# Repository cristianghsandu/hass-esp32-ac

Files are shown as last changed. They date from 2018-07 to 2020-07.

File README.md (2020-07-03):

# ESP32 Home Sensor: AC Control #

## General info ##
This is a small board to add Home Assistant control to your old school AC.  
It uses an ESP32 for WiFi connectivity and IR code sending(via the RMT peripheral).  

This is what it looks like when fully built:  

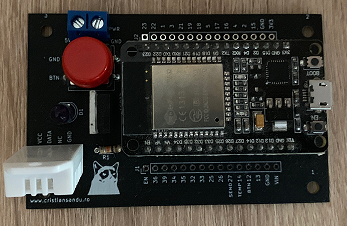
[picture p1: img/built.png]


And this is the bare PCB:  

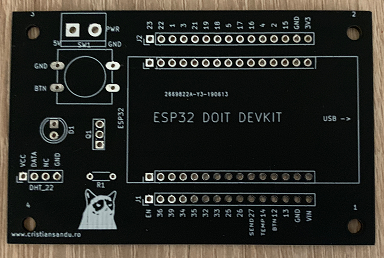
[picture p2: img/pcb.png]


## Building ##
For a Fritzing breadboard schematic see [this Fritzing file](schematic/schematic.fzz).  
For the PCB I used the ESP32 30-pin DoIT devkit board footprint from this [repo](https://github.com/RuiSantosdotme/ESP32-Weather-Shield-PCB).  

The KiCad sources for the PCB are in [this folder](pcb/esp32-ac-board).  

### BOM ###
  
The very few parts you will need are:  

- An ESP32 Doit Devkit v1 (the 30 pin version see [this](https://randomnerdtutorials.com/getting-started-with-esp32/))  
- A NPN transistor in a TO220 package(you could change the design to use a TO92 transistor) like the [2N5296](https://www.mouser.com/ds/2/68/2n5294-46674.pdf)  
- Some male and female pin headers(pitch 2.54'')
- A 12x12mm push button  
- An IR LED
- A DHT22 humidity and temperature sensor  
- A 10k pull up resistor for the DHT22 sensor
- Optional: a 2 pin screw terminal for powering the board externally

### The Code ###

I am using ESP Home to build the firmware [ESP Home](https://esphome.io/).  
The "code" is in this file: [esphome/ac-living.yml](esphome/ac-living.yml).    

### AC Control ###

To control your AC you will need to change the RAW codes in the [config.h](src/config.h) file. I used [AnalysIR](https://www.analysir.com/) to get my raw codes but you could also get them with an Arduinoor even Lirc with irrecord(it's what I initially did). Hardware wise you will either need an Arduino/Raspberry Pi + TSOP4838 receiver(or any other receiver) or maybe an all-in-one solution like the [USB IR Toy](http://dangerousprototypes.com/docs/USB_Infrared_Toy) - which I already had and used.

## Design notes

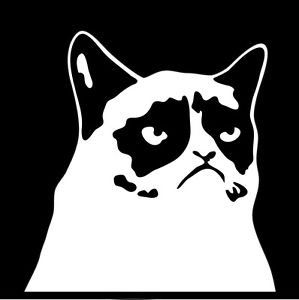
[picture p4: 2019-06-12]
img/grumpy.jpg

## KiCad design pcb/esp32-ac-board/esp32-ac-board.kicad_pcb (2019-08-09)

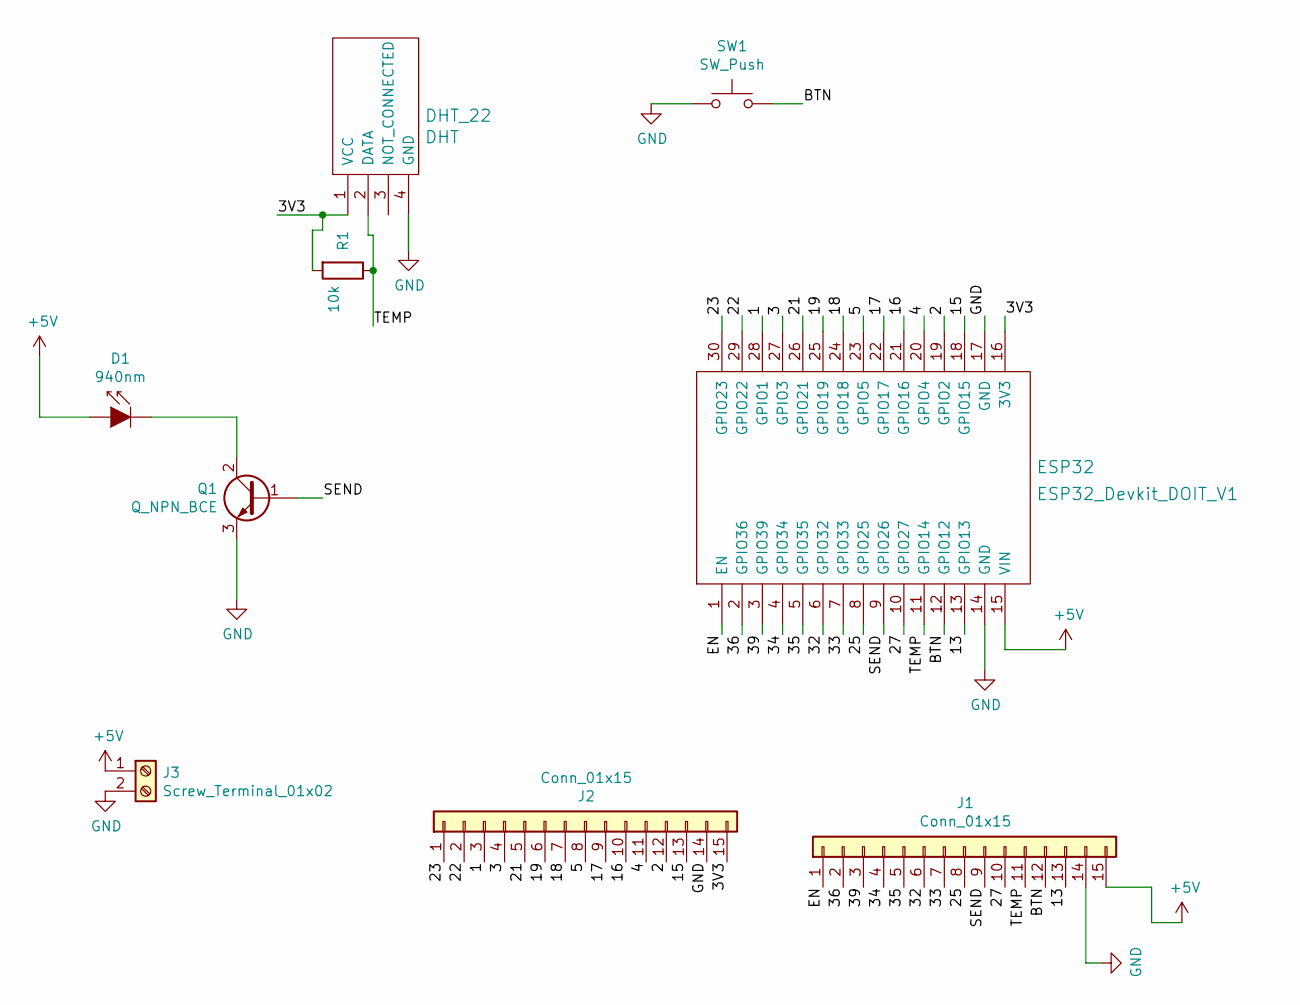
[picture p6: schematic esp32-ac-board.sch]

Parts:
D1: 940nm; LED_D5.0mm_IRGrey
DHT_22: DHT
ESP32: ESP32_Devkit_DOIT_V1
J1, J2: Conn_01x15; PinHeader_1x15_P2.54mm_Vertical
J3: Screw_Terminal_01x02; TerminalBlock_bornier-2_P5.08mm
Q1: Q_NPN_BCE; TO-251-3_Vertical
R1: 10k; R_Axial_DIN0204_L3.6mm_D1.6mm_P5.08mm_Horizontal
SW1: SW_Push; SW_PUSH-12mm_Wuerth-430476085716

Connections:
+5V: D1.2 (A), ESP32.15 (VIN), J1.15, J3.1
/1: ESP32.28 (GPIO1), J2.3
/2: ESP32.19 (GPIO2), J2.12
/3: ESP32.27 (GPIO3), J2.4
/3V3: DHT_22.1 (VCC), ESP32.16 (3V3), J2.15, R1.2
/4: ESP32.20 (GPIO4), J2.11
/5: ESP32.23 (GPIO5), J2.8
/13: ESP32.13 (GPIO13), J1.13
/15: ESP32.18 (GPIO15), J2.13
/16: ESP32.21 (GPIO16), J2.10
/17: ESP32.22 (GPIO17), J2.9
/18: ESP32.24 (GPIO18), J2.7
/19: ESP32.25 (GPIO19), J2.6
/21: ESP32.26 (GPIO21), J2.5
/22: ESP32.29 (GPIO22), J2.2
/23: ESP32.30 (GPIO23), J2.1
/25: ESP32.8 (GPIO25), J1.8
/27: ESP32.10 (GPIO27), J1.10
/32: ESP32.6 (GPIO32), J1.6
/33: ESP32.7 (GPIO33), J1.7
/34: ESP32.4 (GPIO34), J1.4
/35: ESP32.5 (GPIO35), J1.5
/36: ESP32.2 (GPIO36), J1.2
/39: ESP32.3 (GPIO39), J1.3
/BTN: ESP32.12 (GPIO12), J1.12, SW1.2
/EN: ESP32.1 (EN), J1.1
/SEND: ESP32.9 (GPIO26), J1.9, Q1.1 (B)
/TEMP: DHT_22.2 (DATA), ESP32.11 (GPIO14), J1.11, R1.1
GND: DHT_22.4 (GND), ESP32.14 (GND), ESP32.17 (GND), J1.14, J2.14, J3.2, Q1.3 (E), SW1.1
unnamed: D1.1 (K), Q1.2 (C)

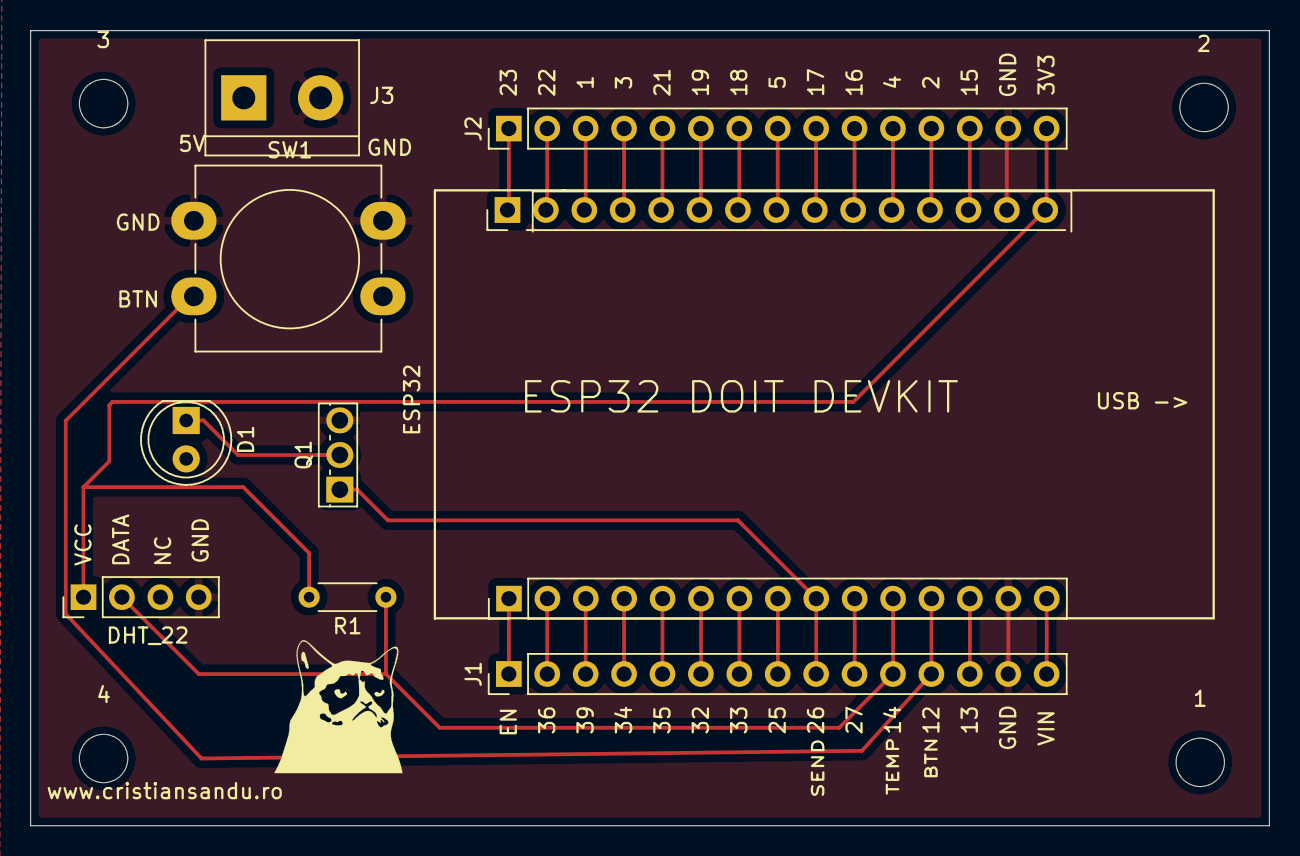
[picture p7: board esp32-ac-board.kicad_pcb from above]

Board: 2 copper layers, 81.9 x 52.6 mm, 14 parts (1 on the bottom side), 30 nets.

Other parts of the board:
1, 2, 3, 4: MountingHole_3.2mm_M3
LOGO: LOGO; Logo

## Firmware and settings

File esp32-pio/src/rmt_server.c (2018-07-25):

/* RMT transmit control over http server.
	* 
	* HTTP server code modified from
	* https://github.com/feelfreelinux/myesp32tests/blob/master/examples/http_server.c
	* That software is distributed under GNU General Public License
	* 
	* RMT code modified from example: rmt_nec_tx_rx
	* That software is distributed under Public Domain (or CC0 licensed, at your option.)
	* 
	* Additional software included in this application is distributed under
	* Public Domain (or CC0 licensed, at your option.)
	* 
	* This software is distributed on an "AS IS" BASIS, WITHOUT WARRANTIES OR
	* CONDITIONS OF ANY KIND, either express or implied.
*/

#include <string.h>
#include "freertos/FreeRTOS.h"
#include "freertos/task.h"
#include "freertos/event_groups.h"
#include "esp_system.h"
#include "esp_wifi.h"
#include "esp_event_loop.h"
#include "esp_log.h"
#include "nvs_flash.h"
#include "driver/gpio.h"
#include "driver/rmt.h"

#include "lwip/sys.h"
#include "lwip/netdb.h"
#include "lwip/api.h"

// FreeRTOS function
#define INCLUDE_vTaskDelay 1

// HTTP responses
const static char http_html_Accepted[] = "HTTP/1.1 202 Accepted\r\nConnection: close\r\n\r\n";
const static char http_html_Not_Allowed[] = "HTTP/1.1 405 Method Not Allowed\r\nConnection: close\r\n\r\n";

// LED on Huzzah32 board
const int LED_BUILTIN = 13;

// used during debug
const static char http_debug1[] = "HTTP/1.1 202 Accepted\r\nContent-type: text/html\r\n\r\n";
const static char http_debug2[] = "<html><head><title>ESP32</title></head><body><pre>";
const static char http_debug3[] = "</pre></body></html>";

// how to connect to my local WiFi
#define WIFI_SSID "***REMOVED***"
#define WIFI_PASS "***REMOVED***"

// RMT values
#define RMT_TX_CHANNEL RMT_CHANNEL_0
#define RMT_TX_GPIO    GPIO_NUM_26
// channel clock period = 0.8 uS?
#define RMT_CLK_DIV    100

// WIFI values
static EventGroupHandle_t wifi_event_group;
const int CONNECTED_BIT = BIT0;

// used when parsing integers from character arrays
typedef struct {
	int num;
	bool good;
} returnIntVal;

// WiFi event handler
static esp_err_t event_handler(void *ctx, system_event_t *event) {
	switch(event->event_id) {
	case SYSTEM_EVENT_STA_START:
		esp_wifi_connect();
		break;
	case SYSTEM_EVENT_STA_GOT_IP:
		xEventGroupSetBits(wifi_event_group, CONNECTED_BIT);
		break;
	case SYSTEM_EVENT_STA_DISCONNECTED:
		/* This is a workaround as ESP32 WiFi libs don't currently
			auto-reassociate. */
		esp_wifi_connect();
		xEventGroupClearBits(wifi_event_group, CONNECTED_BIT);
		break;
	default:
		break;
	}
	return ESP_OK;
}

// initialize WiFi
static void initialise_wifi(void) {
	tcpip_adapter_init();
	wifi_event_group = xEventGroupCreate();
	ESP_ERROR_CHECK( esp_event_loop_init( event_handler, NULL ) );
	wifi_init_config_t cfg = WIFI_INIT_CONFIG_DEFAULT();
	ESP_ERROR_CHECK( esp_wifi_init(&cfg) );
	ESP_ERROR_CHECK( esp_wifi_set_storage(WIFI_STORAGE_RAM) );
	wifi_config_t wifi_config = {
		.sta = {
			.ssid = WIFI_SSID,
			.password = WIFI_PASS,
		},
	};
	ESP_ERROR_CHECK( esp_wifi_set_mode(WIFI_MODE_STA) );
	ESP_ERROR_CHECK( esp_wifi_set_config( WIFI_IF_STA, &wifi_config ) );
	ESP_ERROR_CHECK( esp_wifi_start() );
	printf("WiFi initialized\n");
}

// initialize RMT peripheral for output
// Note that some of these settings can be modified during operation
static void rmt_tx_init() {
	rmt_config_t rmt_tx;
	rmt_tx.rmt_mode = RMT_MODE_TX;
	rmt_tx.channel  = RMT_TX_CHANNEL;
	rmt_tx.gpio_num = RMT_TX_GPIO;
	rmt_tx.mem_block_num = 1;
	rmt_tx.clk_div = RMT_CLK_DIV;
	rmt_tx.tx_config.loop_en = false;
	rmt_tx.tx_config.carrier_duty_percent = 30;
	rmt_tx.tx_config.carrier_freq_hz = 38000;
	rmt_tx.tx_config.carrier_level   = RMT_CARRIER_LEVEL_HIGH;
	rmt_tx.tx_config.carrier_en      = true;
	rmt_tx.tx_config.idle_level      = RMT_IDLE_LEVEL_LOW;
	rmt_tx.tx_config.idle_output_en  = true;
	
	ESP_ERROR_CHECK( rmt_config(&rmt_tx) );
	ESP_ERROR_CHECK( rmt_driver_install(rmt_tx.channel, 0, 0) );
	printf("RMT initialized\n");
}

// find the start of the request body, which follows a blank line
// a blank line is created by two consecutive \n's, ignoring \r's
// more than two consecutive newlines are accepted
// returns the index of the character following the newlines
u16_t find_body( char* buf, u16_t length ) {
	printf("Finding POST body, buffer size %d\n", length);
	// counts number of consecutive newlines
	u16_t newlines = 0;
	// character pointer
	u16_t this_char;
	// the response starts with 'POST ', so start at character 5
	for ( this_char=5; this_char<=length; this_char++ ) {
		if ( buf[this_char] == '\r' ) { continue; }
		if ( buf[this_char] == '\n' ) { newlines++; }
		// only received a single newline, reset counter
		else if ( newlines == 1 ) { newlines = 0; }
		if ( ( newlines > 1 ) && ( buf[this_char] != '\n' ) ) {
			printf("Found body start %d\n", this_char);
			return this_char;
		}
	}
	// body not found
	return 0;
}

// push item onto rmt_item32_t array
// value_index points to: duration0/level0, duration1/level1, ...
//       value_index: 0 1 2 3 4 5 6 7
//   value_index / 2: 0 0 1 1 2 2 3 3
//       items index: 0 0 1 1 2 2 3 3
void pushItem( rmt_item32_t* items, u16_t value_index, bool level, u16_t duration ) {
	u16_t i = value_index / 2;
	// lower 16 bits of the 32-bit item
	if ( value_index % 2 == 0 ) {
		items[i].level0 = level;
		items[i].duration0 = duration;
		// just in case this is the last item, fill up the next entry
		items[i].level1 = level;
		items[i].duration1 = 0;
	}
	// upper 16 bits of the 32-bit item
	else {
		items[i].level1 = level;
		items[i].duration1 = duration;
	}
	printf("Item pushed to RMT data RAM: level %d, duration %u\n", level, duration);
}

// set the clock divisor and carrier clock high/low durations
// set during the decode of RMT data
void set_rmt_frequency( uint16_t div, uint16_t high, uint16_t low ) {
	printf("Set frequency %i, %i, %i\n", div, high, low);
	
	// if clock divisor changes, set to new value
	uint8_t previous_div;
	rmt_get_clk_div( RMT_TX_CHANNEL, &previous_div );
	printf("previous div: %i\n", previous_div);
	if ( (uint8_t) div != previous_div ) {
		rmt_set_clk_div( RMT_TX_CHANNEL, (uint8_t) div );
		printf("set div = %i\n", div);
	}
	
	// set clock high and low times
	// args: channel, carrier_en, high_level, low_level, carrier_level
	rmt_set_tx_carrier( RMT_TX_CHANNEL, true, high, low, RMT_CARRIER_LEVEL_HIGH );
	printf("Reset RMT frequency\n");
}

// returns the number of comma-separated fields in this line,
// including the first field, the line type designation
u16_t count_values( char* buf, u16_t start, u16_t end ) {
	u16_t count = 0;
	u16_t pointer;
	for ( pointer=start; pointer<=end; pointer++ ) {
		if ( buf[pointer] == ',' ) { count++; }
	}
	return count + 1;
}

// get the n-th field from the comma-separated line
// the first numerical field is index = 0
returnIntVal get_number( char* buf, u16_t start, u16_t end, int count ) {
	returnIntVal n;
	n.num = 0;
	n.good = true;
	bool is_neg = false;
	u16_t this_char = start;
	u16_t commas = 0;
	printf("get_number: look for %d\n", count);
	
	// count values separated by commas
	if ( count > 0 ) {
		while( this_char++ <= end ) {
			if ( buf[this_char] == ',' ) { commas++; }
			if ( commas == count ) { break; }
		}
		// point to the character after the comma
		this_char++;
	}
	
	// did not find the value
	if ( commas < count ) {
		printf("get_number not found\n");
		n.good = false;
		return n;
	}
	
	// is the number negative?
	if ( buf[this_char] == '-' ) {
		is_neg = true;
		this_char++;
	}
	
	// get numerical characters
	while( (this_char <= end) && 
		(buf[this_char]>47) && 
		(buf[this_char]<58 ) ) {
		n.num = ( 10 * n.num ) + ( buf[this_char] - 48 );
		this_char++;
	}
	
	// return
	if ( is_neg ) { n.num = -1 * n.num; }
	// printf("get_number found %d\n", n.num);
	return n;
}

// write frequency and clock data to the RMT peripheral
void send_freq( char* buf, u16_t start, u16_t end ) {
	// frequency settings: [Division Ratio, High Duration, Low Duration]
	int freq[3] = {0, 0, 0};
	bool good = true;
	returnIntVal n;
	printf("send_freq %d to %d\n", start, end);
	
	// division ratio, 8-bit register
	n = get_number( buf, start, end, 0 );
	if ( (n.good) && (n.num>0) && (n.num<256) ) {
		freq[0] = n.num;
		// printf("get_num 0 %d\n", n.num);
	}
	else { good = false; }
	
	// clock high duration, 16-bit register
	n = get_number( buf, start, end, 1 );
	if ( (n.good) && (n.num>0) && (n.num<65536) ) {
		freq[1] = n.num;
		// printf("get_num 1 %d\n", n.num);
	}
	else { good = false; }
	
	// clock low duration, 16-bit register
	n = get_number( buf, start, end, 2 );
	if ( (n.good) && (n.num>0) && (n.num<65536) ) {
		freq[2] = n.num;
		// printf("get_num 2 %d\n", n.num);
	}
	else { good = false; }
	
	// set register values
	if ( good ) {
		set_rmt_frequency( freq[0], freq[1], freq[2] );
		//printf("Set frequency %d, %d, %d\n", freq[0], freq[1], freq[2]);
	}
}

// write duration data to the RMT RAM
void send_duration( char* buf, u16_t start, u16_t end ) {
	u16_t count, c;
	returnIntVal val;
	bool good = true;
	
	// the number of comma-separated numeric values on this line
	count = count_values(buf, start, end);
	
	// each 32-bit RMT item holds 2 duration/level values
	// divide count of numerical values by 2 get required number of 32-bit values
	// multiply by 4 to get bytes
	//            count: 0 1 2 3 4  5  6  7  8
	//        count + 1: 1 2 3 4 5  6  7  8  9
	//  (count + 1) / 2: 0 1 1 2 2  3  3  4  4
	//    RMT RAM items: 0 1 1 2 2  3  3  4  4
	//     malloc bytes: 0 4 4 8 8 12 12 16 16
	
	// number of bytes in the 32-bit RMT item array
	size_t size = 4 * ( ( count + 1 ) / 2 );
	rmt_item32_t* items = (rmt_item32_t*) malloc(size);
	printf("Row has %i values, allocated %i bytes\n", count, size);
	printf("Starts with %c, ends with %c\n", buf[start], buf[end]);
	
	// create an object for RMT RAM values
	for ( c=0; c<count; c++ ) {
		val = get_number( buf, start, end, c );
		if ( val.good ) {
			// negative values create no RMT output pulses
			if ( val.num < 0 ) {
				pushItem( items, c, false, -1*val.num );
			}
			// positive values create RMT output pulses
			else {
				pushItem( items, c, true, val.num );
			}
		}
		// cannot write this value to RMT RAM
		else { good = false; }
	}
	if ( good ) {
		// args: channel, rmt_item, item_num wait_tx_done
		rmt_write_items(RMT_TX_CHANNEL, items, size, true);
		printf("Write %d durations\n", count);
	}
	else { printf("ERROR in transmit data\n"); }
	// free up memory
	free( items );
}

// FreeRTOS constant portTICK_PERIOD_MS
// example usage: vtaskDelay( 500 / portTICK_PERIOD_MS )
void delay_task( char* buf, u16_t start, u16_t end ) {
	returnIntVal val;
	val = get_number( buf, start, end, 0 );
	if ( ( val.good ) && ( val.num > 0 ) ) {
		vTaskDelay( val.num / portTICK_PERIOD_MS );
		printf("Delay %d\n", val.num);
	}
}

// get lines of RMT commands from POST request
// start is first valid character of the request
// end is the last character of the request
void get_request_line( char* buf, u16_t start, u16_t end ) {
	u16_t line_start;
	u16_t this_char = start;
	line_start = start;
	while ( this_char <= end ) {
		// found end of line, decode it
		if ( ( buf[this_char] == '\r' ) || 
			 ( buf[this_char] == '\n' ) || 
			 ( this_char == end ) ) {
			printf("Line %d to %d\n", line_start, this_char);
			
			// ignore newline character at end of this line
			if ( ( buf[this_char] == '\r' ) || ( buf[this_char] == '\n' ) ) {
				this_char--;
			}
			// is there anything to decode?
			if ( ( this_char - line_start ) > 1 ) {
				if ( ( buf[line_start] == 'c' ) && ( buf[line_start+1] == ',' ) ) {
					printf("clock\n");
					// send frequency data to the RMT peripheral
					send_freq( buf, line_start+2, this_char );
				}
				else if ( ( buf[line_start] == 't' ) && ( buf[line_start+1] == ',' ) ) {
					printf("transmit\n");
					// turn on the visible LED
					gpio_set_level(LED_BUILTIN,1);
					
					// send duration data to the RMT peripheral
					send_duration( buf, line_start+2, this_char );
					
					gpio_set_level(LED_BUILTIN,0);
				}
				else if ( ( buf[line_start] == 'd' ) && ( buf[line_start+1] == ',' ) ) {
					printf("delay\n");
					// delay this task
					delay_task( buf, line_start+2, this_char );
				}
				else {
					// do not recognize this line
					printf("unknown line\n");
				}
			}
			// advance to the character AFTER the end of the line
			if ( this_char < end ) { this_char++; }
			
			// skip possible multiple \r and \n
			while ( this_char <= end && 
				( buf[this_char] == '\r' || buf[this_char] == '\n' ) ) {
				this_char++;
			}
			line_start = this_char;
		}
		this_char++;
	}
}

// Process an HTTP POST request
static void http_server_netconn_serve(struct netconn *conn) {
	struct netbuf *inbuf;
	char *buf;
	u16_t buflen;
	u16_t rmt_start;
	err_t err;
	
	// Read the data from the port, blocking if nothing yet there.
	err = netconn_recv(conn, &inbuf);
	
	printf("Start looking for POST request\n");
	
	if (err == ERR_OK) {
		netbuf_data(inbuf, (void**)&buf, &buflen);
		
		// Is this an HTTP POST command?
		if ( buflen>5 && 
			buf[0]=='P' && buf[1]=='O' && buf[2]=='S' && buf[3]=='T' ) {
			
			printf("Decoding POST request\n");
			
			// process the POST request
			rmt_start = find_body( buf, buflen );
			if ( rmt_start > 0 ) {
				get_request_line( buf, rmt_start, buflen );
			}
			
			// HTTP Response to POST request
			netconn_write(conn, http_html_Accepted, sizeof(http_html_Accepted)-1, NETCONN_NOCOPY);
			
			// HTTP Debug response, instead of the normal response, echoes the entire request
			//netconn_write(conn, http_debug1, sizeof(http_debug1)-1, NETCONN_NOCOPY);
			//netconn_write(conn, http_debug2, sizeof(http_debug1)-1, NETCONN_NOCOPY);
			//netconn_write(conn, buf, buflen, NETCONN_NOCOPY);
			//netconn_write(conn, http_debug3, sizeof(http_debug1)-1, NETCONN_NOCOPY);
			
			// gpio_set_level(LED_BUILTIN,0);
		}
		// do not accept non-POST requests
		else {
			netconn_write(conn, http_html_Not_Allowed, sizeof(http_html_Not_Allowed)-1, NETCONN_NOCOPY);
		}
	}
	// Close the connection
	netconn_close(conn);
	
	// Delete the buffer
	netbuf_delete(inbuf);
}

// HTTP server
static void http_server(void *pvParameters) {
	struct netconn *conn, *newconn;
	err_t err;
	conn = netconn_new(NETCONN_TCP);
	netconn_bind(conn, NULL, 80);
	netconn_listen(conn);
	do {
		err = netconn_accept(conn, &newconn);
		if (err == ERR_OK) {
			http_server_netconn_serve(newconn);
			netconn_delete(newconn);
		}
	} while(err == ERR_OK);
	netconn_close(conn);
	netconn_delete(conn);
}

void app_main() {
	// set board built-in LED as an output
	gpio_pad_select_gpio(LED_BUILTIN);
	gpio_set_direction(LED_BUILTIN, GPIO_MODE_OUTPUT);
	
	// Initialize NVS flash storage
    nvs_flash_init();
    
    // Initialize the RMT peripheral for output
    rmt_tx_init();
    
    // Initialize WiFi
    initialise_wifi();
    
    // HTTP server task
    xTaskCreate(&http_server, "http_server", 2048, NULL, 5, NULL);
}

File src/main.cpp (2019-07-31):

#include "config.h"

#include <esphome.h>
#include <OneButton.h>

#if ENABLE_IR
#include <ESP32_IR_Remote.h>
#endif

#include <binary_state.h>

using namespace esphome;

#if ENABLE_IR
ESP32_IRrecv irrecv;
#endif

OneButton button(BUTTON_PIN, true);

switch_::MQTTSwitchComponent *mqttAcState;
BinaryState *acState;

void turnAcOnOff()
{
    if (!acState || !mqttAcState)
    {
        return;
    }

    digitalWrite(LED_BUILTIN, HIGH);
#if ENABLE_IR
    irrecv.sendIR((int *)data_ac, data_ac_len);
#endif
    digitalWrite(LED_BUILTIN, LOW);
}

void switchAcState()
{
    acState->invert_state();
    mqttAcState->publish_state(acState->get_state());
}

void setupHomeAssistant()
{
    output::BinaryOutput *output = new BinaryState([](bool state) {
        static bool initialSync = true;
        if (initialSync) {
            initialSync = false;
            return;
        }
        
        turnAcOnOff();

        ESP_LOGCONFIG(TAG, "AC state: %d", state);
    });
    acState = (BinaryState *)output;

    auto acSwitch = App.make_output_switch("AC", output);

    auto sensor = App.make_dht_sensor("Living Temperature", "Living Humidity", DHT22_PIN, 2000);
    sensor->set_dht_model(sensor::DHT_MODEL_DHT22);

    mqttAcState = new switch_::MQTTSwitchComponent(acSwitch);

    button.attachClick(switchAcState);
}

void setupPins()
{
    pinMode(LED_BUILTIN, OUTPUT);

    // Debouncing time
    button.setDebounceTicks(50);

#if ENABLE_IR
    irrecv.ESP32_IRsendPIN(SEND_PIN, 0);
    irrecv.initSend();
#endif
}

void setup()
{
    App.set_name("AC-Living");
    App.init_log();

    App.init_wifi(ssid, password);
    App.init_ota()->start_safe_mode();
    App.init_mqtt(mqttServer, "", "");
    App.init_api_server();

    setupHomeAssistant();

    setupPins();

    App.setup();
}

void loop()
{
    button.tick();

    App.loop();
}

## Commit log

2018-07-21 add button
2018-07-21 ir led on/off
2018-07-21 increase power?
2018-07-26 switch to Arduino
2018-07-26 convert to arduino code
2018-07-26 schematic, initial changes
    [schematic.fzz]
2018-07-27 switch to unified DHT lib
2018-07-27 tweak de;ay
2018-07-28 schematic: dht22
    [schematic.fzz]
2018-07-28 switch to DHTesp library
2018-08-08 one button lib
2018-10-07 readd esp32_ir_remote
2018-10-07 really add esp32 ir lib
2018-10-07 add sensor
2018-10-07 push button
2018-10-09 almost fix button
2018-10-09 add second AC switch
2018-10-15 switch to one button
2018-10-15 working prototype
2019-06-09 PCB design
    [esp32-ac-board.kicad_pcb, esp32-ac-board.sch]
2019-06-10 update schematic
2019-06-10 Fix schematic, redo PCB
    [esp32-ac-board.kicad_pcb, esp32-ac-board.sch, schematic.fzz]
2019-06-10 update button connection
    [schematic.fzz]
2019-06-11 Use 5V signal like in https://hackaday.com/2016/11/17/creating-a-pcb-in-everything-kicad-part-1/
    [esp32-ac-board.kicad_pcb, esp32-ac-board.sch]
2019-06-11 Add traces
    [esp32-ac-board.kicad_pcb, esp32-ac-board.sch]
2019-06-11 Copper fills
    [esp32-ac-board.kicad_pcb, esp32-ac-board.sch]
2019-06-12 Attempt at logo
    [esp32-ac-board-B_Cu.gbr, esp32-ac-board-B_Mask.gbr, esp32-ac-board-B_Paste.gbr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]
2019-06-12 fix logo
    [esp32-ac-board.kicad_pcb]
2019-06-12 add screw terminal for power
    [esp32-ac-board.kicad_pcb, esp32-ac-board.sch]
2019-06-12 v0.1 sent to JLCPCB.com
    [esp32-ac-board-B_Cu.gbr, esp32-ac-board-B_Mask.gbr, esp32-ac-board-B_Paste.gbr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]
2019-06-13 attempt to rotate diode
    [esp32-ac-board.kicad_pcb, esp32-ac-board.sch]
2019-06-15 circuit experiments
    [mosfet-ir-led.kicad_pcb, mosfet-ir-led.sch]
2019-06-27 Fix label
    [esp32-ac-board.kicad_pcb]
2019-06-28 fix button holes
    [esp32-ac-board.kicad_pcb, esp32-ac-board.sch]
2019-07-01 add light switch
2019-07-31 remove unused button
2019-08-05 document BOM
2019-08-05 fix BOM
2019-08-05 10k resistor
2019-08-09 rebuild gerber
    [esp32-ac-board-B_Cu.gbr, esp32-ac-board-B_Mask.gbr, esp32-ac-board-B_Paste.gbr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]
2019-08-09 refresh gerber
    [esp32-ac-board-B_Cu.gbr, esp32-ac-board-B_Mask.gbr, esp32-ac-board-B_Paste.gbr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]
